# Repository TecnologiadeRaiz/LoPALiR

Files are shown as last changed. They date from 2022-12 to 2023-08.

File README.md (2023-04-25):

<!--
SPDX-FileCopyrightText: 2023 Tecnología de Raíz <tecnologiaderaiz@disroot.org>

SPDX-License-Identifier: CC-BY-NC-4.0
-->

# LoPALiR
This section contains Files supporting the LoPaLiR (Local Prodiction o f Antennas for LibreRouters) project.


Here you can find design files, a circular waveguide calculator, and complementary files to the [TdR Blog](http://tdr.libre.org.ar)

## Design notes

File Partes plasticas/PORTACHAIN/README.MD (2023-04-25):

<!--
SPDX-FileCopyrightText: 2023 Tecnología de Raíz <tecnologiaderaiz@disroot.org>

SPDX-License-Identifier: CC-BY-NC-4.0
-->

Acá se encuentran los diseños de "portachains", las partes plásticas que sostienen los cables de las antenas.

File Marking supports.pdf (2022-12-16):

## Marking metal backets

## Workspace:

For this process we use a table and a wooden block that helps us to make the punching with a custom-made template and then punching the metal brackets

## For this work we need:

- A firm table
- A wooden block
- A paper template with the measurements corresponding to the
- A 2mm thick metal plate of 50mm x 80mm with a metal plate of 2mm thickness
50mm x 80mm with a 90º fold of 50mm x 50mm
- Hammer
- Punch.

## How is it done?

With the metal plate, we use the work table with a wooden block that holds the metal bracket to mark it with the paper template that refers where to make the perforations.

With the help of a previously created template we proceed to mark the metal Brackets with a punch and hammer.

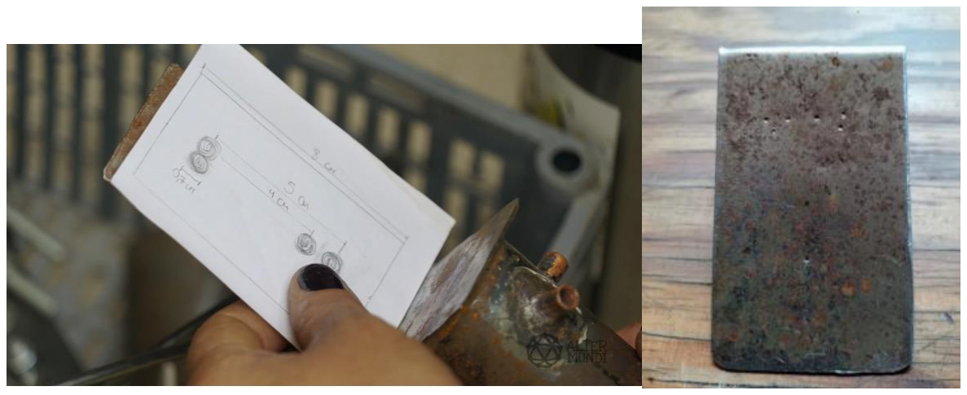
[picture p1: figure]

## Recommendations or warnings:

To make this jig, we use clamps called "threaded u" that metal bracket the bracket to a pipe. We suggest using the "threaded u" to mark the place where the holes will be drilled.

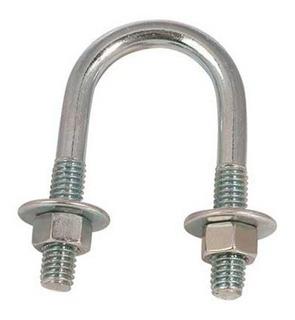
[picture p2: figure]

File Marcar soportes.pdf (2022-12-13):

## Marcar soportes

### Espacio de trabajo:

Para este proceso utilizamos una mesa y un taco de madera que nos ayuda a realizar el punzonado con una plantilla hecha a medida para luego perforar los soportes.

### Para este trabajo necesitamos:

Una mesa firme un taco de madera una plantilla de papel con las medidas corrrespondientes a la perforación una plancha de metal de 2mm de grosor de 50mm x 80mm con un pliegue a 90º de 50mm x 50mm punzon martillo.

### ¿Cómo se hace?

Con la plancha de metal, utilizamos la mesa de trabajo con un taco de madera que sostiene el soporte para marcarlo, con la plantilla de papel que refiere donde hacer las perforaciones.

Con la ayuda de una plantilla previamente creada procedemos a marcar los soportes con un punzon y martillo.

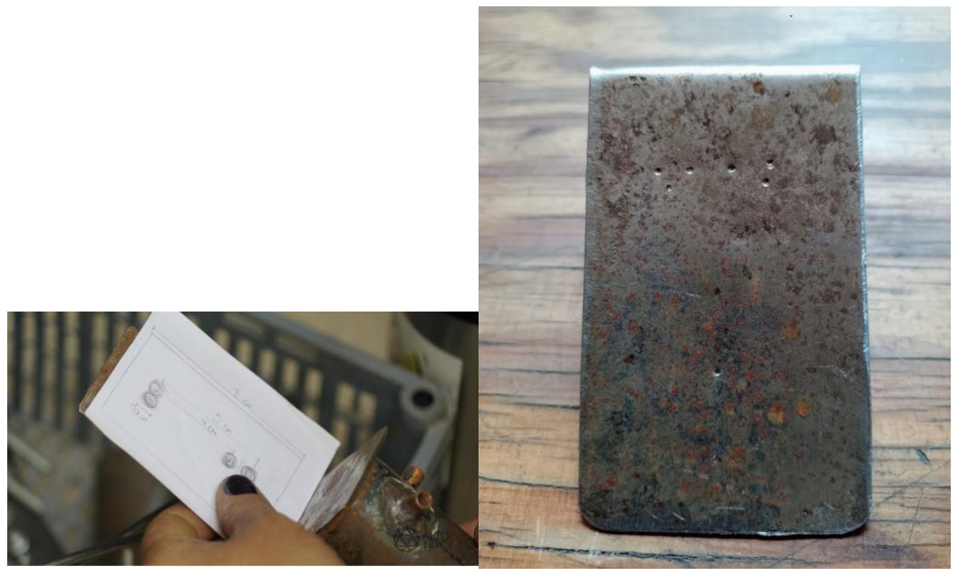
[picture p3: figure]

### Recomendaciones o advertencias:

Para realizar esta plantilla, utilizamos abrazaderas llamadas "u roscada" que permiten sostener el soporte a un caño. Sugerimos utilizar las "u roscadas" para marcar el lugar donde se realizarán las perforaciones.


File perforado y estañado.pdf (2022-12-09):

## Perforado y estañado de perforaciones en guía de ondas

### Espacio de trabajo

Para esta tarea, utilizamos la mesa de trabajo central, con la morza instalada.

### Para este trabajo necesitamos:

- Taladro de mano
- Soplete zinguero
- Estaño
- Plantilla de perforación

### ¿Cómo se hace?

Con el caño previamente cortado a 130 mm procedemos a preparar banco de trabajo para perforar la guia de ondas

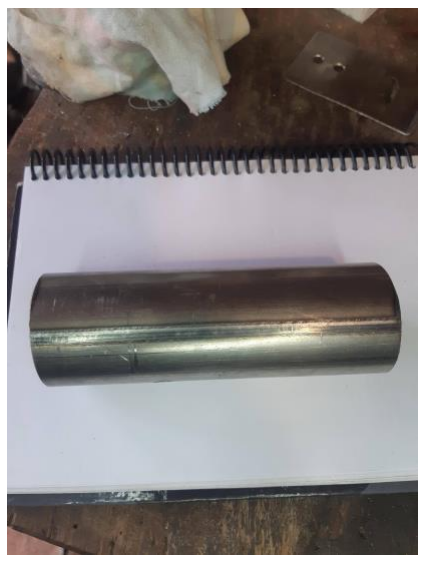
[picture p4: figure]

Con ayuda de un molde de papel que utilizamos como plantilla.

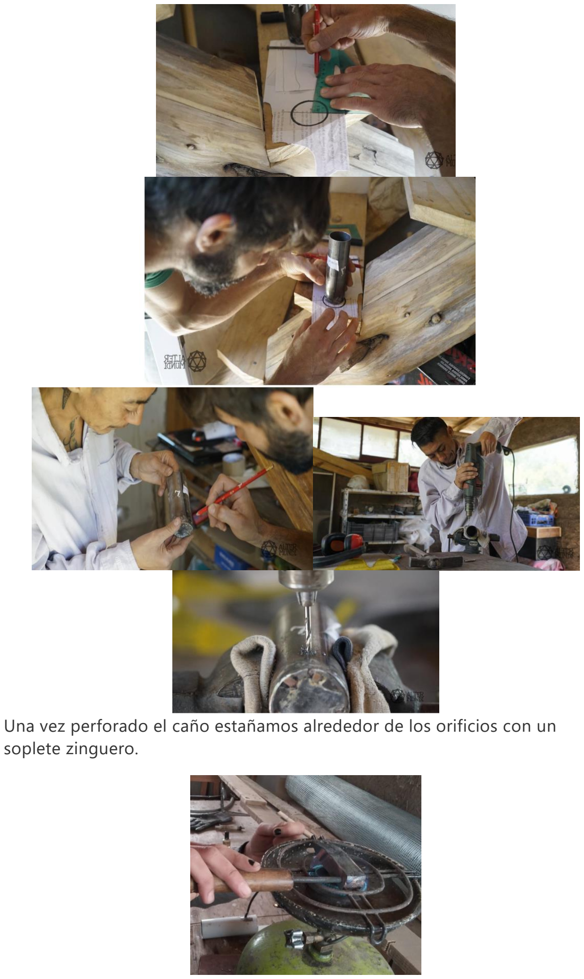
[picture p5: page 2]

Una vez perforado el caño estañamos alrededor de los orificios con un soplete zinguero.

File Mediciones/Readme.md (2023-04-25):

<!--
SPDX-FileCopyrightText: 2023 Tecnología de Raíz <tecnologiaderaiz@disroot.org>

SPDX-License-Identifier: CC-BY-NC-4.0
-->

Aquí encontrarán los programas de mediciones desarrollado por @Santiago Piccinini y @Nicolás Echaniz en colaboración con AlterMundi.
También estarán los archivos complementarios

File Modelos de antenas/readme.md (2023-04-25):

<!--
SPDX-FileCopyrightText: 2023 Tecnología de Raíz <tecnologiaderaiz@disroot.org>

SPDX-License-Identifier: CC-BY-NC-4.0
-->

Acá vas a encontrar los modelos de las antenas.

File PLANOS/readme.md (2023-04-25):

<!--
SPDX-FileCopyrightText: 2023 Tecnología de Raíz <tecnologiaderaiz@disroot.org>

SPDX-License-Identifier: CC-BY-NC-4.0
-->

Aca estan los planos de las distintas partes de la antena.

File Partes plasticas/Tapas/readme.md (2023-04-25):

<!--
SPDX-FileCopyrightText: 2023 Tecnología de Raíz <tecnologiaderaiz@disroot.org>

SPDX-License-Identifier: CC-BY-NC-4.0
-->

Acá van a encontrar los modelos 3D de las tapas.

Para abrirlo es necesario tener instalado FreeCad --> https://www.freecadweb.org/downloads.php

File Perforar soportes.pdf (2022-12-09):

## Perforar soportes

### Espacio de trabajo:

Utilizamos la mesa de trabajo central con el taladro de mano, y una plantilla diseñada para tal fin.

### Para este trabajo necesitamos:

Mecha 6mm
Lima redonda y plana (para eliminar rebarbas) Taladro de mano
Morza
Plantilla de papel con medidas

### ¿Cómo se hace?

Con los soportes previamente marcados, procedemos a perforar con el taladro de mano, sosteniendo el soporte con la morza.
Una vez realizadas las perforaciones, limamos las rebarbas.

### Recomendaciones o advertencias

Recomendamos utilizar un taco de madera que la morza pueda sujetar el soporte y permita apoyarlo encima para perforar sobre él.

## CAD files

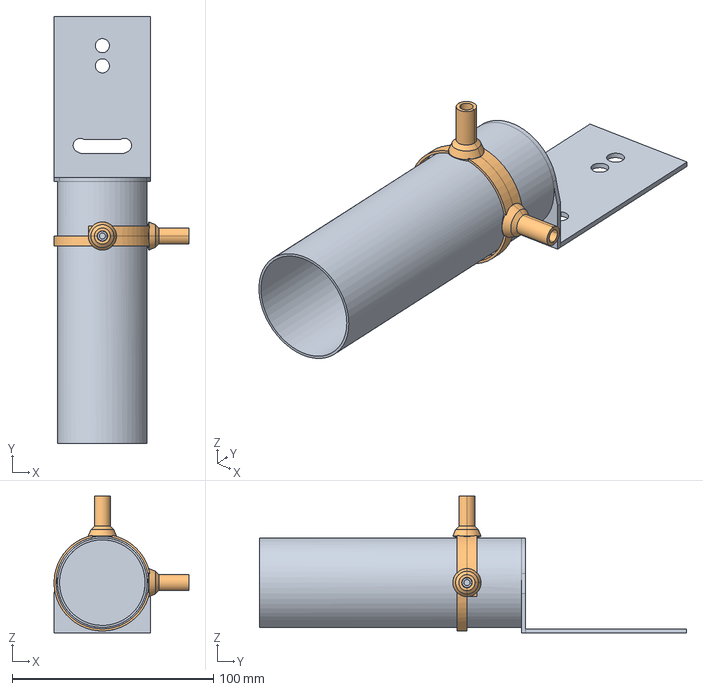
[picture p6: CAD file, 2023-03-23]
Modelos de antenas/WAVEGUIDE-v4.FCStd
67.0 x 212.0 x 68.0 mm
waveguide-v3
portachain

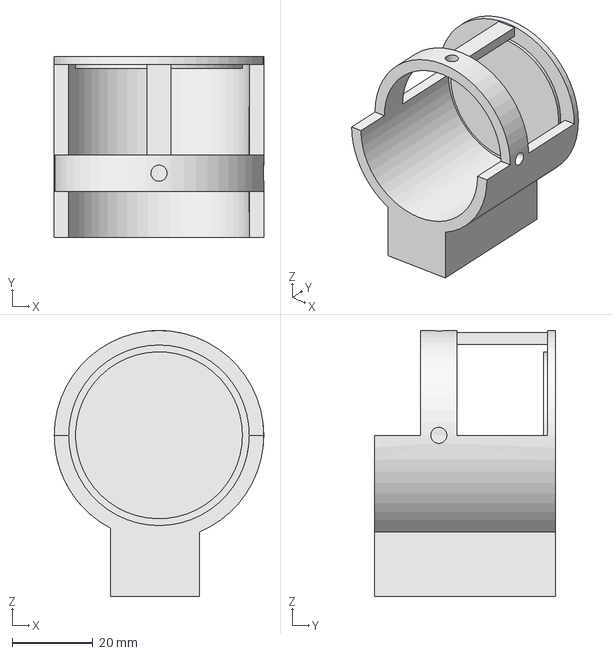
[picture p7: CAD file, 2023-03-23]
Partes plasticas/Molde de perforacion/MOLDE DE PERFORACION GUIA DE ONDAS-v2.FCStd
52.0 x 45.0 x 66.0 mm

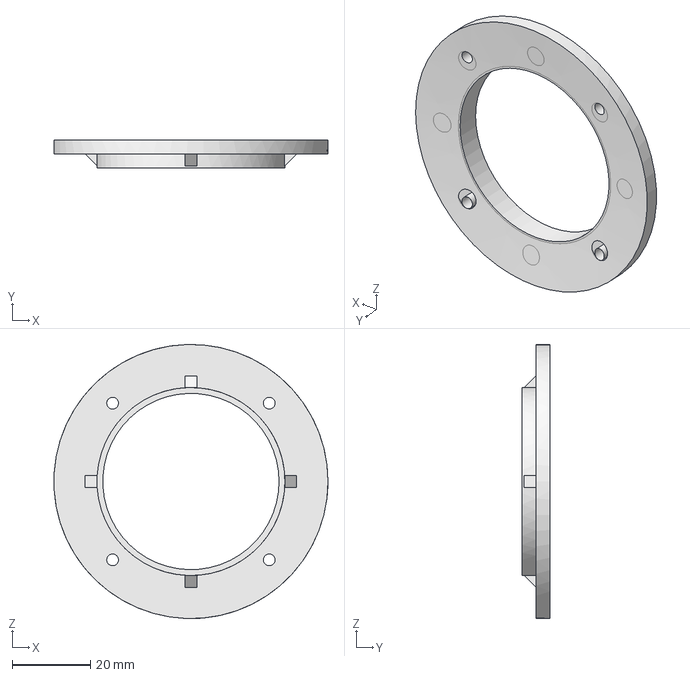
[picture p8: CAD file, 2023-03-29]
Partes plasticas/Portareflector y Soportes de Parábola/SOPORTE PARÁBOLA - v1.FCStd
70.0 x 7.21 x 70.0 mm

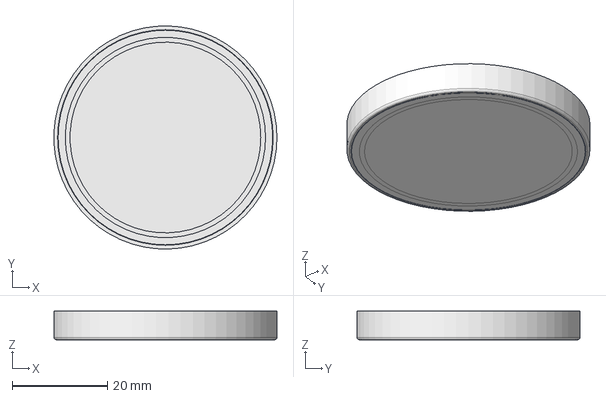
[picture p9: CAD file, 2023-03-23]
Partes plasticas/Tapas/TAPA-v1.FCStd
46.8 x 46.8 x 6.00 mm

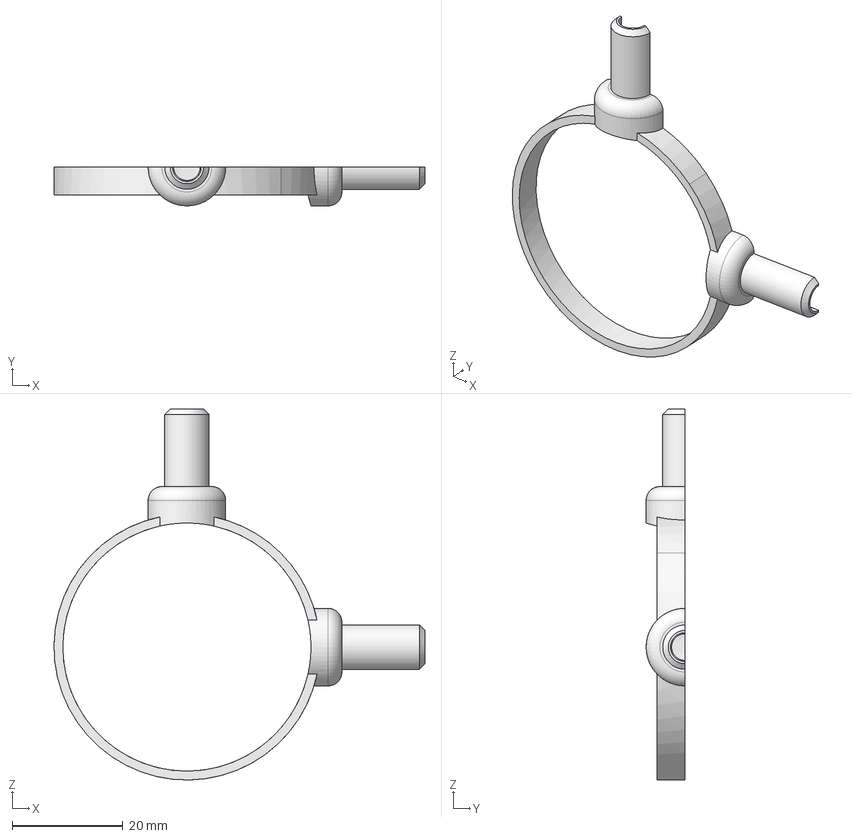
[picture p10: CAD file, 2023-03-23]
Partes plasticas/PORTACHAIN/PORTACHAIN FRONTAL-v4.FCStd
67.0 x 7.00 x 67.0 mm

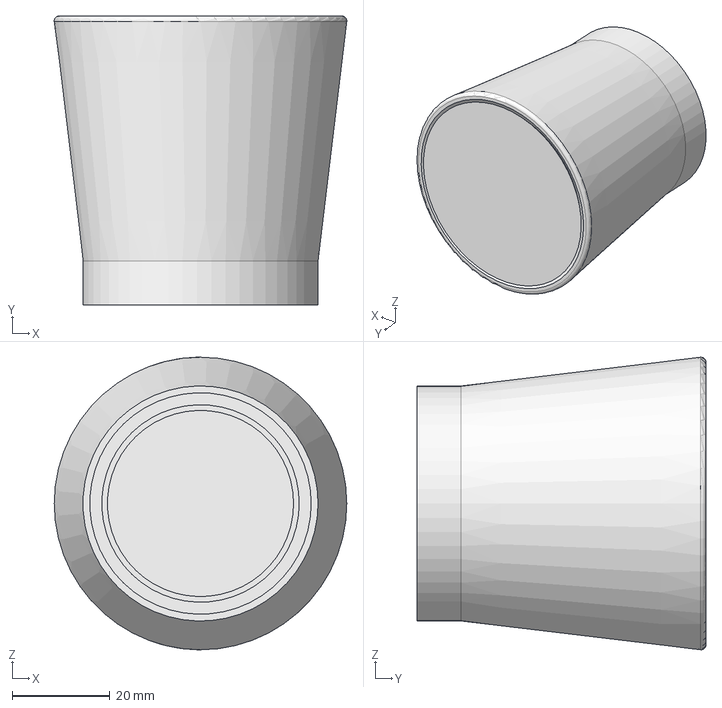
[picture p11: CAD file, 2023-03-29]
Partes plasticas/Portareflector y Soportes de Parábola/PORTAREFLECTOR.FCStd
59.7 x 59.0 x 59.7 mm

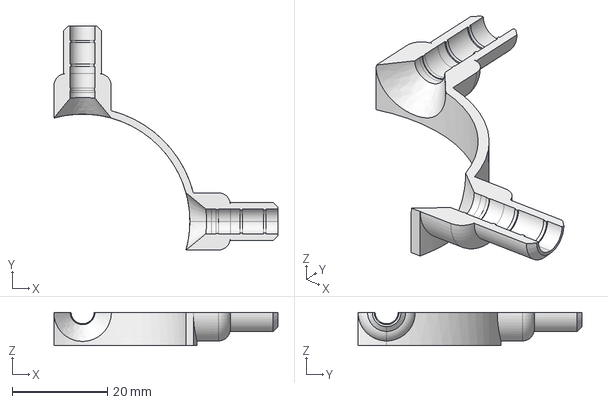
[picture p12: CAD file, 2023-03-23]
Partes plasticas/PORTACHAIN/PORTACHAIN TRASERO-V5.FCStd
47.0 x 47.0 x 7.00 mm

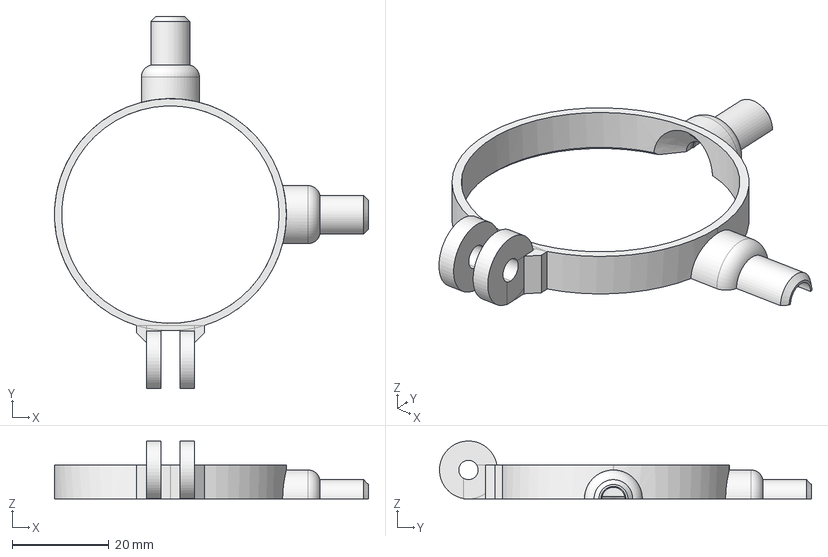
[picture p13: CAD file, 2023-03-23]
Partes plasticas/PORTACHAIN/PORTACHAIN-FRONTAL-V5.FCStd
65.0 x 77.0 x 12.0 mm

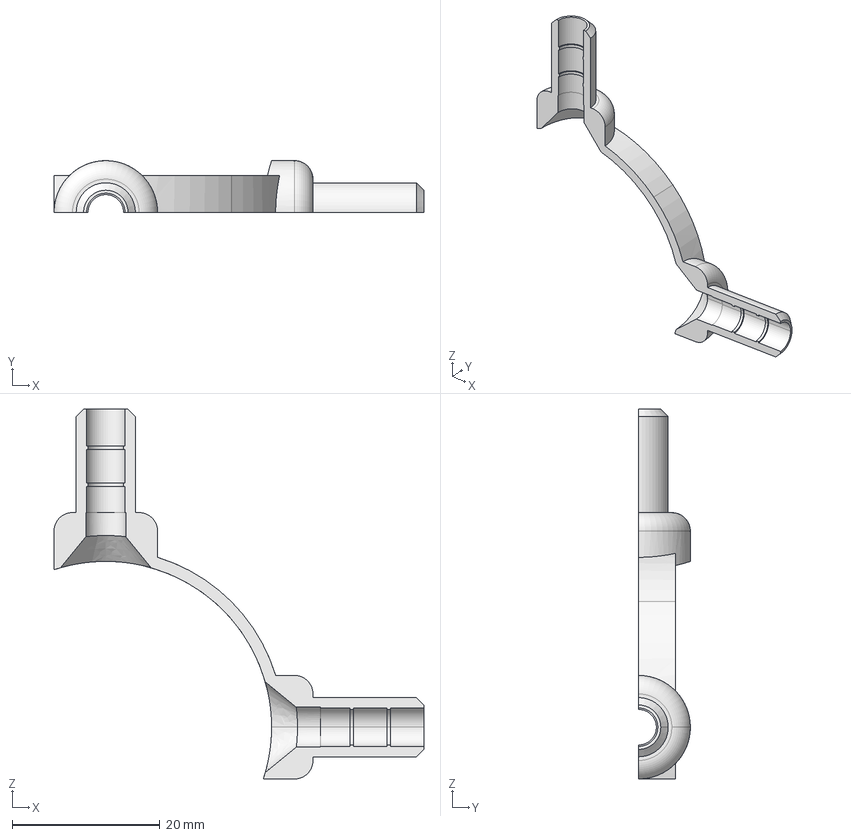
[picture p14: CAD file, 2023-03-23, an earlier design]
Partes plasticas/PORTACHAIN/PORTACHAIN TRASERO-v4.FCStd
50.0 x 7.00 x 50.0 mm

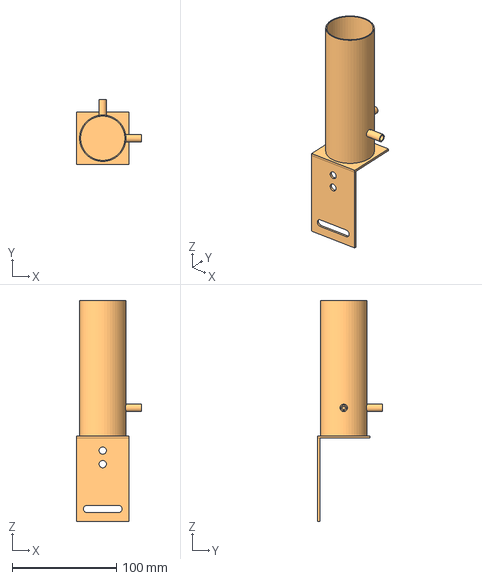
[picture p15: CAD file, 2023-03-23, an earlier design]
Modelos de antenas/WAVEGUIDE-v1.FCStd
62.0 x 62.0 x 212.0 mm
coper-portachain-2
Waveguide-v1

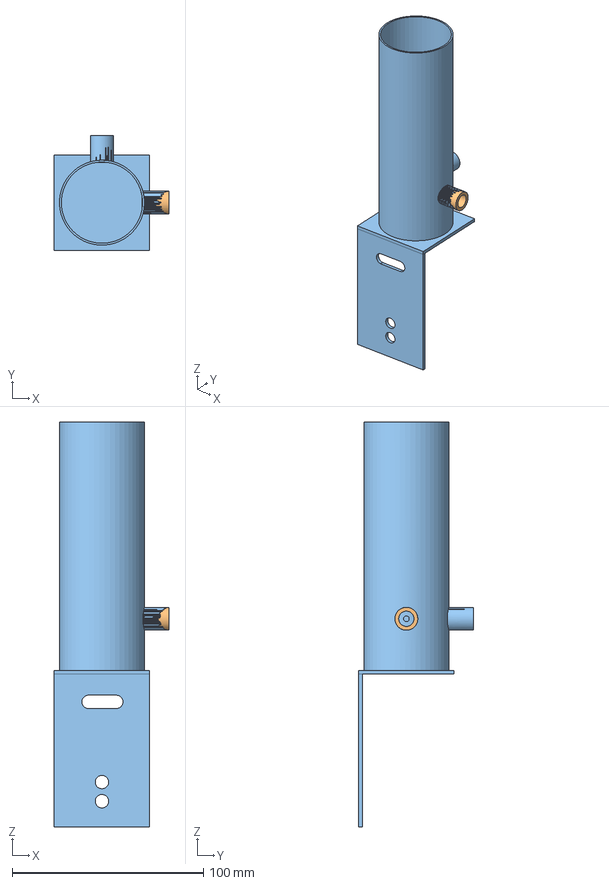
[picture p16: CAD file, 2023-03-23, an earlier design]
Modelos de antenas/WAVEGUIDE-v2.FCStd
60.0 x 60.1 x 212.0 mm
resine-container-1
resine-container-2
waveguide-v2

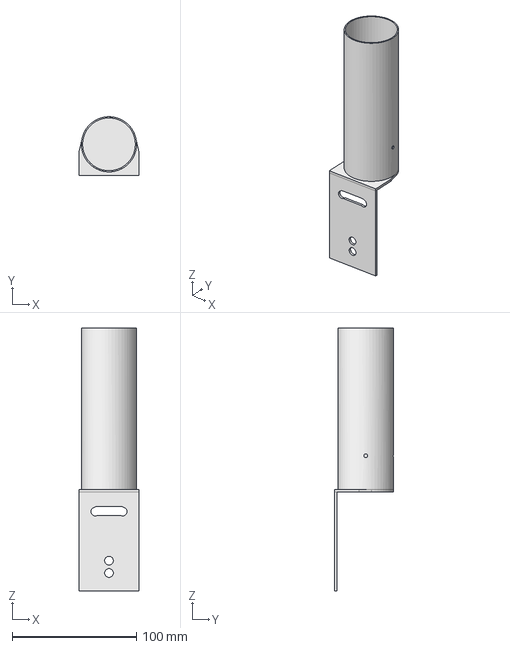
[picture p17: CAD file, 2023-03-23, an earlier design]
Modelos de antenas/WAVEGUIDE-v3.FCStd
48.0 x 47.2 x 212.0 mm

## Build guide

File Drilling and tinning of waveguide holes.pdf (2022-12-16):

# Drilling and tinning of waveguide holes

## Workspace

For this task, we use the central work table, with the mortise installed.

## For this work we need:

- Hand drill
- Zinguero torch
- Tin
- Drilling template

## How is it done?

With the pipe previously cut to 130 mm, we proceed to prepare the workbench to drill the waveguide.

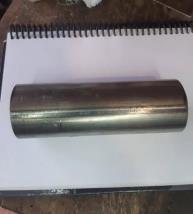
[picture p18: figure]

With the help of a paper mold that we use as a template.

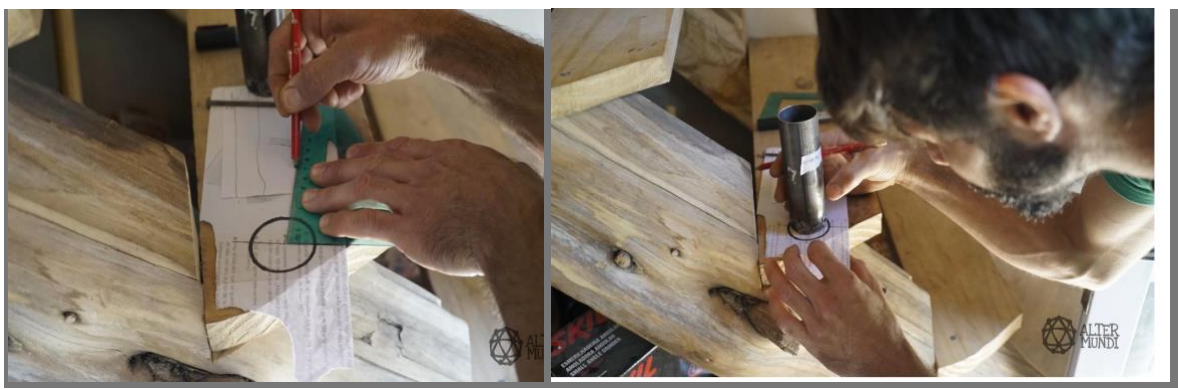
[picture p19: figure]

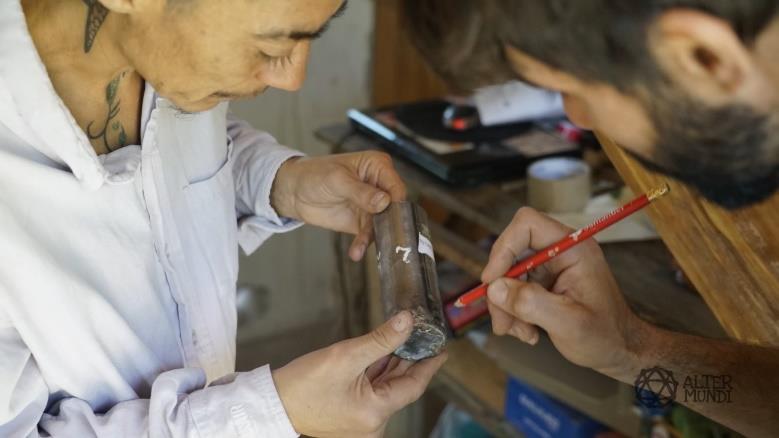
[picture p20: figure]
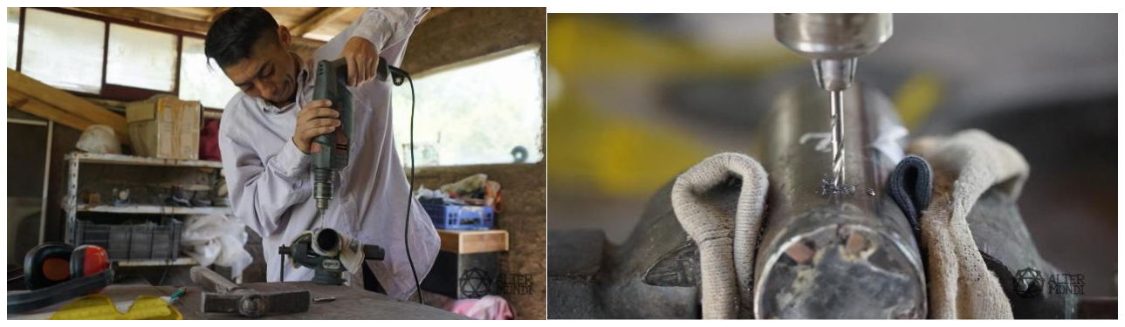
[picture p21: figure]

Once the pipe has been drilled, we tin around the holes with a blowtorch.

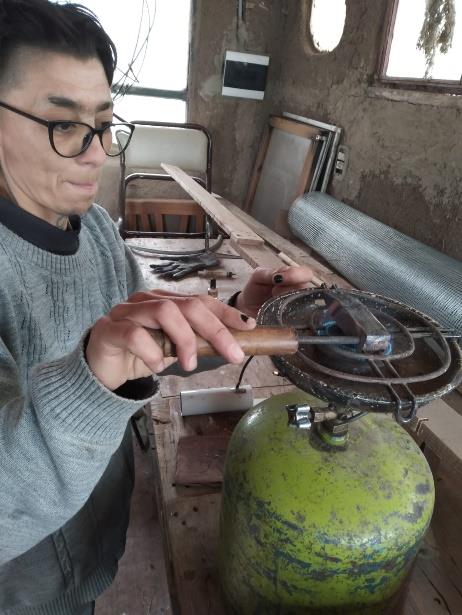
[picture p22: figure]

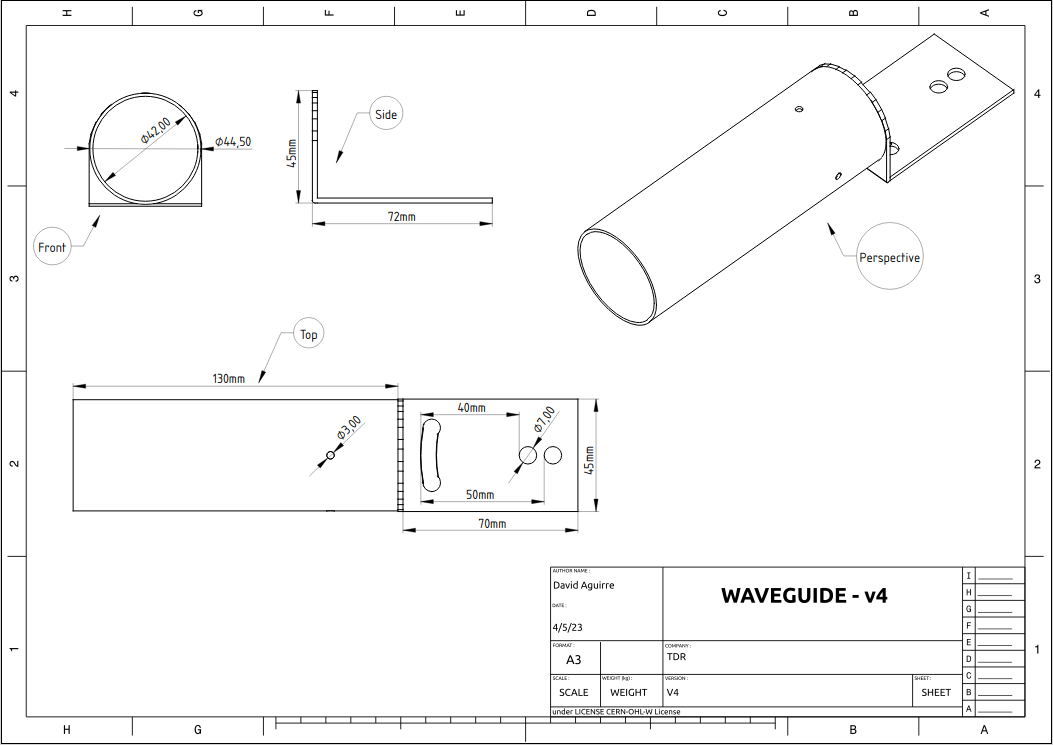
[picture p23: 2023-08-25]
PLANOS/WAVEGUIDE-V4.png

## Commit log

2022-09-22 Add files via upload
    Agregados los FCStd (CADs) y el Calculador (ODS) de la guía de ondas
    [WAVEGUIDE-v0.1.FCStd, WAVEGUIDE-v1.FCStd, WAVEGUIDE-v2.FCStd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]
2022-10-26 Delete Planos Guia de ondas.pdf
    Plano repetido
2022-10-26 Actualizacion de planos y versiones
    [MOLDE DE PERFORACION GUIA DE ONDAS-v2.FCStd, PORTACHAIN FRONTAL-v4.FCStd, PORTACHAIN TRASERO-v4.FCStd]
2022-12-09 actualizacion de diseños 3D
    diseños con partes mas claras y nombradas
    [WAVEGUIDE-v1.FCStd, WAVEGUIDE-v2.FCStd, WAVEGUIDE-v3.FCStd]
2022-12-13 ACTUALIZACION CON CORRECCIONES
    [Metalbraket-v3.FCStd, WAVEGUIDE-v1.FCStd, WAVEGUIDE-v2.FCStd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]
2022-12-16 Add files via upload
    marking metal brackets
2022-12-21 actualización
    texto de creative commons
2022-12-29 Add files via upload
    material especificaciones tecnicas
2023-01-11 Add files via upload
    Agrego archivos para mediciones
2023-01-17 Delete PORTACHAIN FRONTAL-v4.FCStd
    cambio de ubicacion de estos archivos
    [PORTACHAIN FRONTAL-v4.FCStd]
2023-01-17 Delete PORTACHAIN TRASERO-v4.FCStd
    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
    [PORTACHAIN TRASERO-v4.FCStd]
2023-02-28 Actualización de versiones
    [PORTACHAIN TRASERO-V5.FCStd, PORTACHAIN-FRONTAL-V5.FCStd]
2023-03-22 Delete MOLDE DE PERFORACION GUIA DE ONDAS-v2.FCStd
    SERAN AGREGADOS NUEVAMENTE EN LA CARPETA CORRESPONDIENTE
    [MOLDE DE PERFORACION GUIA DE ONDAS-v2.FCStd]
2023-03-22 Delete Metalbraket-v3.FCStd
    SERAN AGRAGADOS NUEVAMENTE EN LA CARPETA CORRESPONDIENTE
    [Metalbraket-v3.FCStd]
2023-03-22 Delete WAVEGUIDE-v1.FCStd
    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
    [WAVEGUIDE-v1.FCStd]
2023-03-22 Delete WAVEGUIDE-v2.FCStd
    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
    [WAVEGUIDE-v2.FCStd]
2023-03-22 Delete WAVEGUIDE-v3.FCStd
    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
    [WAVEGUIDE-v3.FCStd]
2023-03-22 Delete WAVEGUIDE-v4.FCStd
    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
    [WAVEGUIDE-v4.FCStd]
2023-03-23 Add files via upload
    Actualizacion de licencias.
    [MOLDE DE PERFORACION GUIA DE ONDAS-v2.FCStd]
2023-03-27 Rename Plano Molde de perforacion-v2.svg to MOLDE DE PERFORACION - V2.svg
2023-03-29 Rename Partes plasticas/Portareflector/readme.md to Partes plasticas/Portareflector y Soportes de Parábola/readme.md
2023-04-25 agrego licencias a los archivos de LoPALiR
    [circular_waveguide_tuneado.ods]
2023-08-25 actualizacion de plano
